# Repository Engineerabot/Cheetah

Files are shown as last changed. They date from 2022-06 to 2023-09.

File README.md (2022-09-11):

# README

Introducing Raza is an open source hardware and software engineering project.

## Why is this project important

We want to create inspirational experiences. We want to work where engineering meets art, perhaps more art than engineering. Creation has a way of making us and others feel good. 

## How do I get started

Thank you for considering helping us develop Introducing Raza! We can use your help! Whether you are an expert artist, expert engineer, or a beginner, we could use your help!

## Installation 

If you would like to help with mechanically designing Raza, then join the Mechanical Team.  Our mechanical repository is housed within this github repository.  After joining the Mechanical Team, we will grant you access to our repository.  [Cheetah](https://github.com/Engineerabot/Introducing-Raza).  
  
### Modelio

Download Modelio Open Source from [here](https://www.modelio.org/downloads/download-modelio.html).  Once installed, open Modelio, select file and switch the workspace to point at the Modelio folder within your project clone.

### Solidworks

We have transitioned to Solidworks from Fusion 360.  

## License
[GPLv3](https://www.gnu.org/licenses/gpl-3.0.en.html)

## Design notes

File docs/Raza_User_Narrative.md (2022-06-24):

# User Narrative

Chris has been watching the clock for the last 40 mins.  "Why do I even come to this class? I never get anything out of it,"  Chris wonders. "He might say something that I need to know though.  What if he asked me a question?  I have no idea what he's been talking about lately. It is dark back here, I wonder if he can even see me back here.  I should probably try to listen, or at least look like I'm listening.  If I left early I could go read the textbook and learn this stuff in half the time, that would be more helpful then just sitting here."   

Chris anxiously looks at the exit door.  "It's only 20 feet away.  On the count of three I'm going to get up and walk over to it.  One, two... but if I left early, everyone would watch me walk out.  The professor would surely stop the lecture and look at me.  What if I dropped something?  That'd be terrible.  Could I sink into the floor and slither out the door Grinch style?  Is that possible?  How did the Grinch slide along the ground like that?"  Chris can feel his hands getting sweaty as his anxiousness grows.  "If I wait for the end of class, someone might try to talk to me.  Then I would have to deal with people in the hallway too.  Augh, why did I come today!?"  

Finally the class ends.  The students get up and orderly leave the classroom.  Chris pretends to gather his books, and waits for the other students to file out of the classroom.  Careful not to make eye contact with anyone, he grabs his bag and makes his way to the exit.   

The hallway is unusually clear as Chris tries to make his way through without getting caught up in an awkward conversation.  He notices a group of students gathered around the atrium, which creates an easy path to the doors.  Chris makes a break for it.  Unusual movement within the atrium catches Chris's eye.  Looking through the crowd, he sees the most remarkable creature.  Wham!  Chris's bag hits the ground.  With his bag, Chris drops all of his anxieties, all of his insecurities, all of concerns.  He pushes his way through the crowd of students and comes eye to eye with, what looks like, a cheetah.   

The cheetah walks along the window with strength and power.  It demands complete control of its environment. Muscles flexing with every step, the spine and tail naturally moving back and forth. The long slender body ready to turn and pounce or turn and run at any moment.   It's unpredictability keeps everyone on edge, it's beauty keeps everyone entranced.  Chris follows it along the window, matching it step for step.  He is careful to keep a half step behind.  Chris admires the beauty of the body, the narrow waist, the broad chest, the black tear markings on the face, the long fur on the back of the neck.  "It's barely older than a cub," Chris whispers.  The eyes are the most powerful feature of all.  There is power and confidence deep in those eyes, power and confidence in its soul. 

Chris has never seen a real life cheetah before.  Why is it here?  How did it get here?  Chris didn't know and didn't care.  Looking closely, Chris notices that it is a mechanical robot.  It is really much more than a robot, it is a work of art.  It is mechanical work of art.  This intrigues Chris even more.  "Who was the artist?   The detail of the face, the smooth movement of the body, the muscle detail, it seems so complex, yet so simple.  It is more natural than robotic, more art than engineering."  Zach watches it as it walks up and down the atrium for what seems like 5 minutes.  Darkness has now set in on the atrium, making the cheetah harder to see.

Looking down at his watch, Chris walks over to his bag and looks down at it.  With a deep breath, he picks up his bag, throws it over his shoulder and walks off.   Although, now with more fire in his spirit, and more power and confidence in his soul.

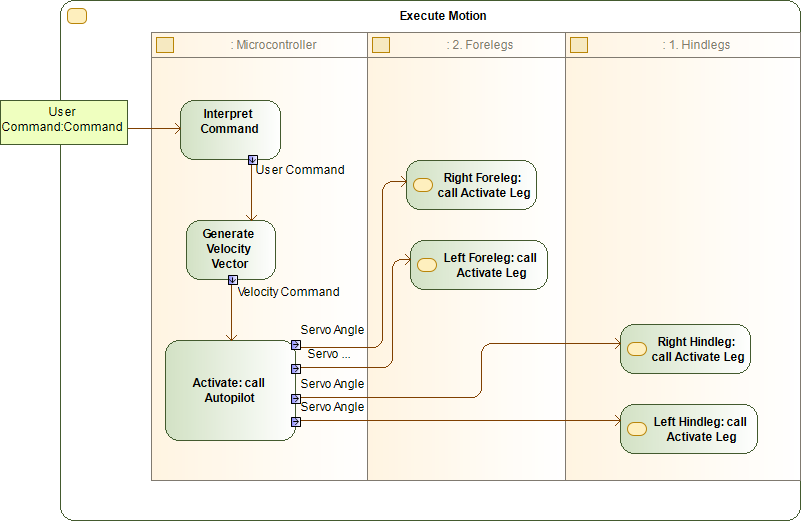
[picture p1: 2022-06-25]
modelio/Raza/doc/structure/img/4146f8e3-a1ea-4b1f-bf91-cede069ed973.png

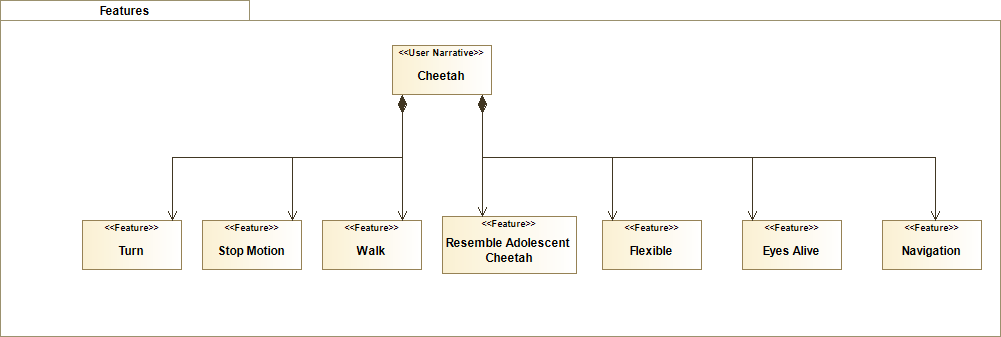
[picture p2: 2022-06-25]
modelio/Raza/doc/CheetahDoc/img/c8a9e4ff-c5fc-48f4-94d7-1af237ac6b6f.png

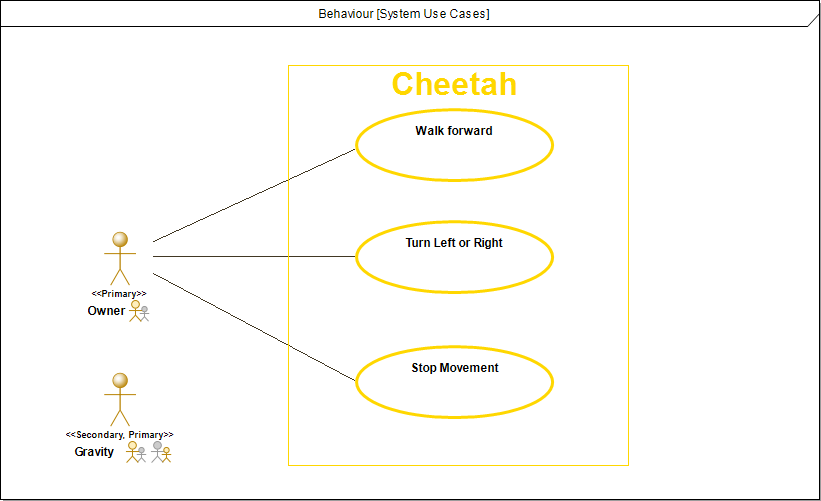
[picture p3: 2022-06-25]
modelio/Raza/doc/structure/img/6b453999-337c-4d21-a7c6-6fcb22df0617.png

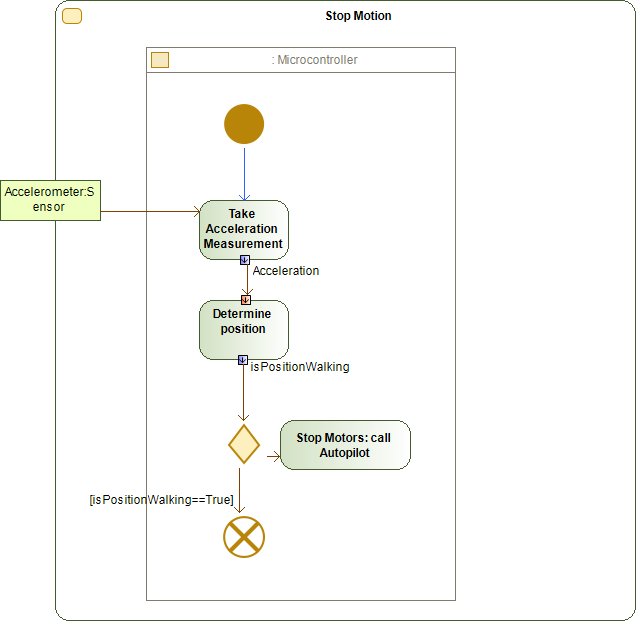
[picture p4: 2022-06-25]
modelio/Raza/doc/structure/img/0b002623-2319-4de4-a623-0d722e94e6e2.png

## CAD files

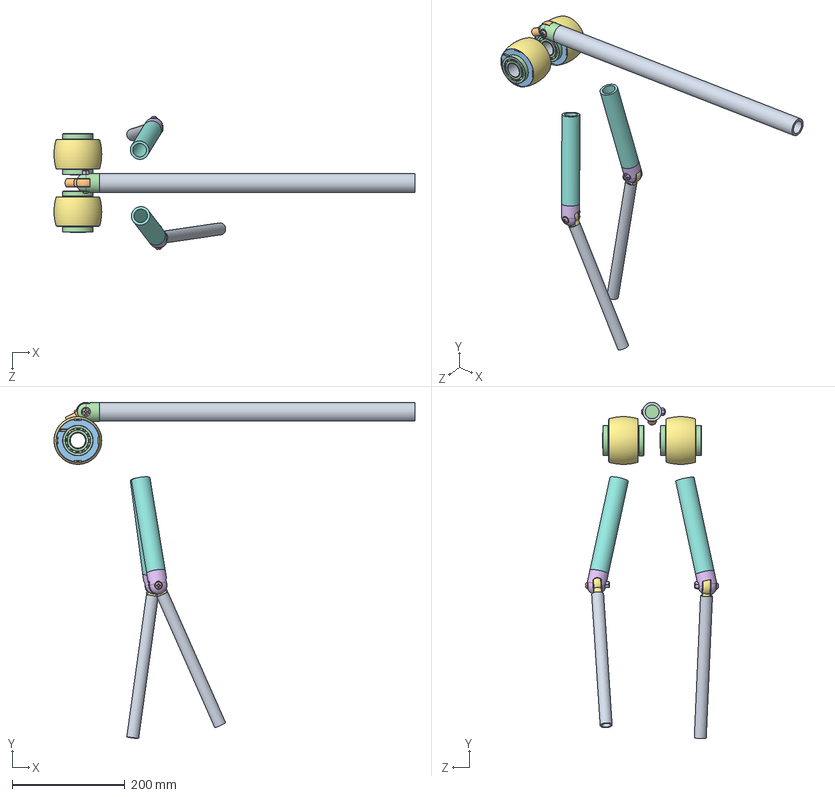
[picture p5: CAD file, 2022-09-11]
design/Level 1/Raza.SLDASM
639.2 x 595.4 x 236.1 mm
Spine
Inner Torso Joint
Knee Joint Pad x 6
Outer Torso Joint
90279A546_Steel Decorative Round Head Phillips Screws x 3
90640A129_Low-Strength Steel Nylon-Insert Locknut x 3
Outer Hip Joint x 2
Inner Hip Joint x 2
Hip Bar x 2
6910-2RS-EZO x 4
Hip Cap x 4
60355K211_Ball Bearing x 4
9271K664_Torsion Spring x 4
Outer Knee Joint x 2
Inner Knee Joint x 2
Femur x 2
Tibia x 2

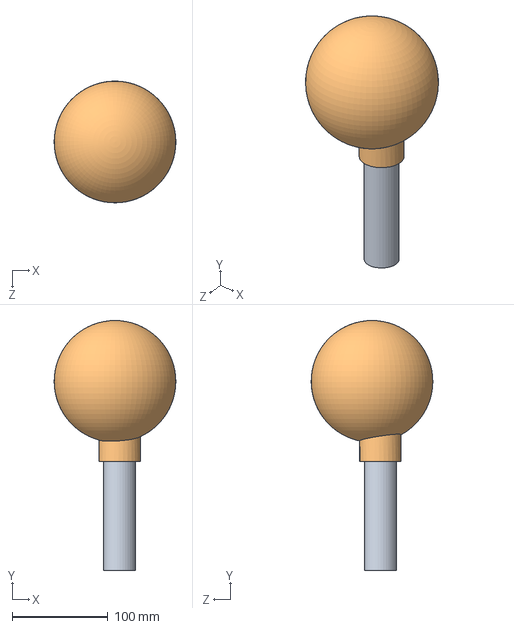
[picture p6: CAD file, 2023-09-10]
design/Level 2/Head Mechanics.SLDASM
127.0 x 260.8 x 126.9 mm
Neck
Skull

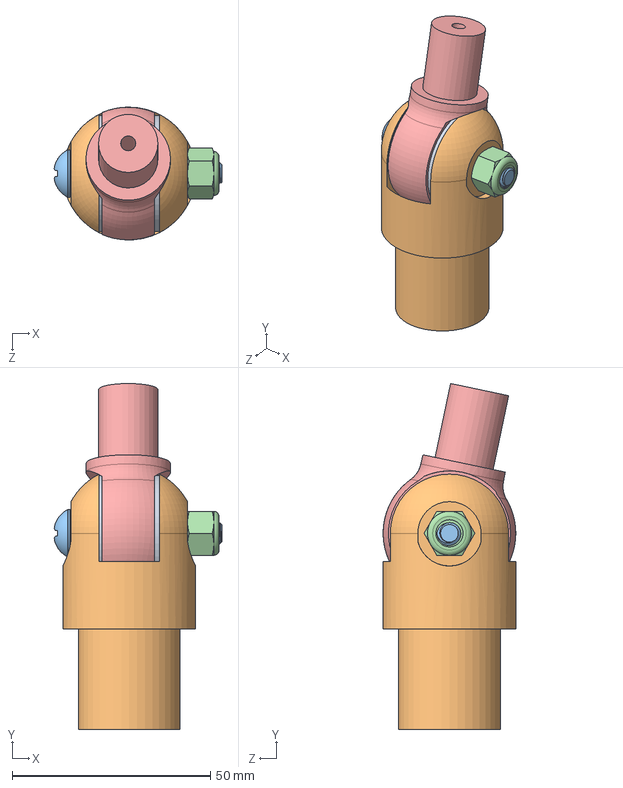
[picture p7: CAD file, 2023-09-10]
design/Level 3/Torso Joint.SLDASM
42.3 x 87.3 x 33.5 mm
Knee Joint Pad x 2
Outer Torso Joint
90279A546_Steel Decorative Round Head Phillips Screws
90640A129_Low-Strength Steel Nylon-Insert Locknut
Inner Torso Joint

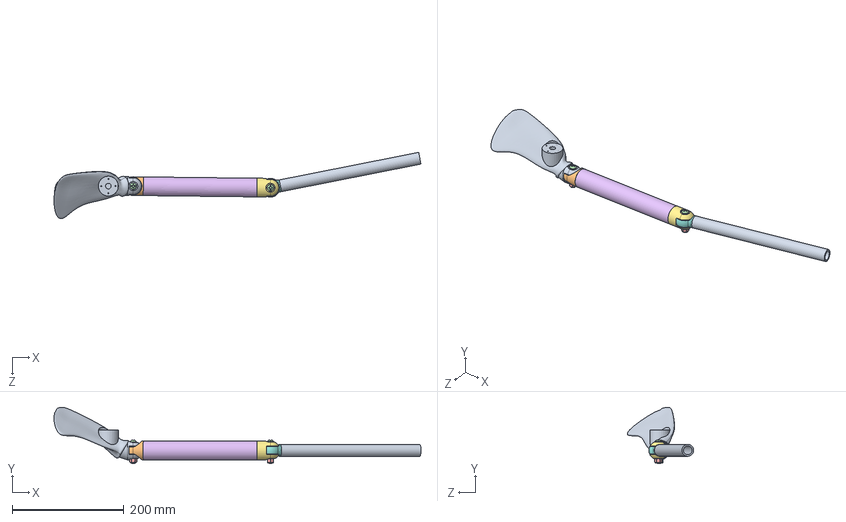
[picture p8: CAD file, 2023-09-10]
design/Level 2/Foreleg Mechanics - Left.SLDASM
655.8 x 100.7 x 118.4 mm
Scapula - Left
Inner Neck Joint
Knee Joint Pad x 4
90279A546_Steel Decorative Round Head Phillips Screws x 2
90640A129_Low-Strength Steel Nylon-Insert Locknut x 2
Humerus
Outer Torso Joint
Inner Torso Joint
Radius

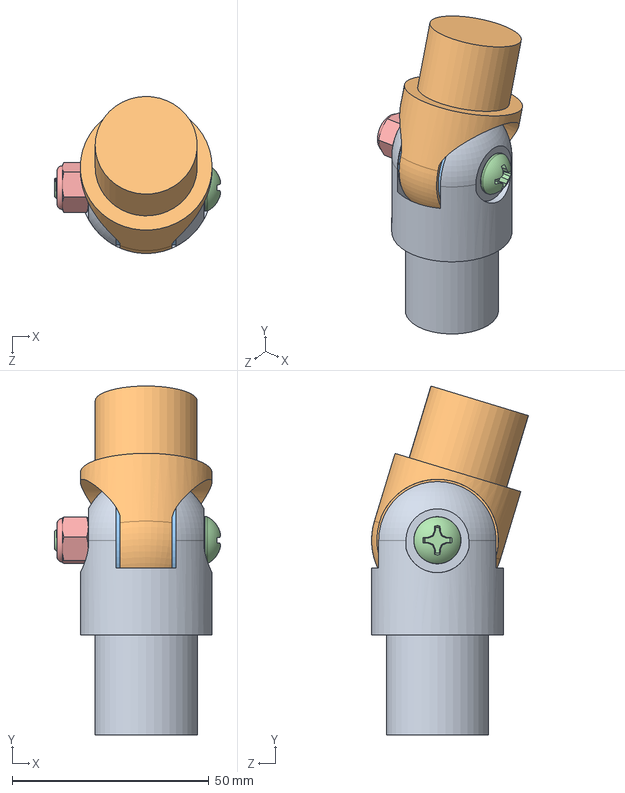
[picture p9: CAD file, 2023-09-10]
design/Level 3/Neck Joint.SLDASM
42.3 x 88.8 x 39.9 mm
Outer Torso Joint
Inner Neck Joint
Knee Joint Pad x 2
90279A546_Steel Decorative Round Head Phillips Screws
90640A129_Low-Strength Steel Nylon-Insert Locknut

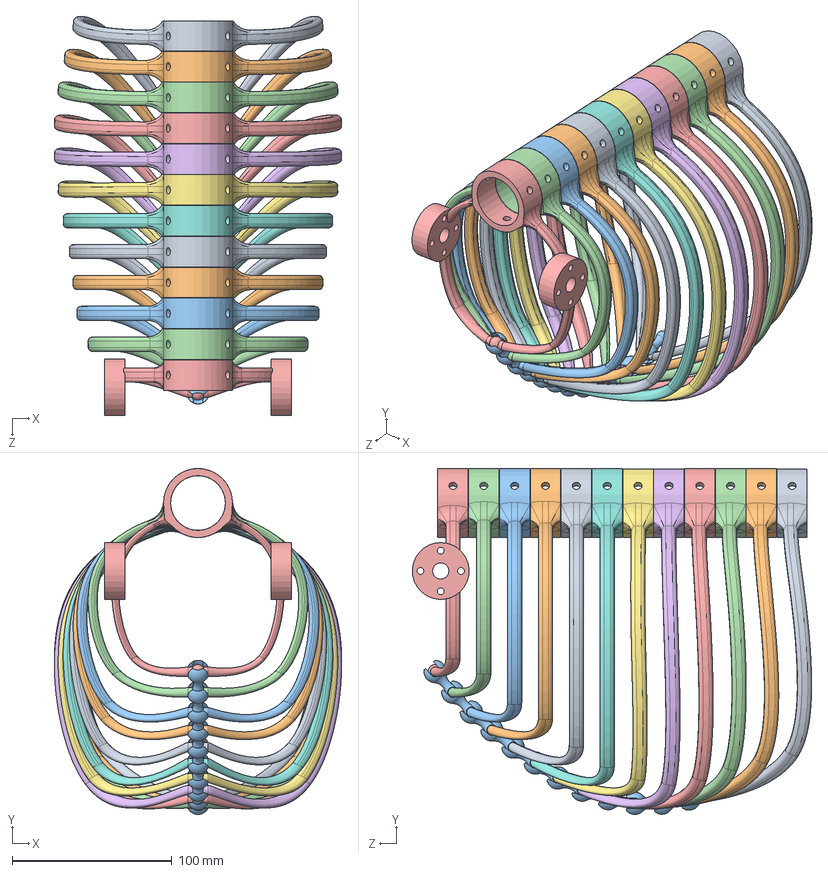
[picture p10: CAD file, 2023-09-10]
design/Level 3/Rib Cage.SLDASM
179.8 x 216.4 x 249.7 mm
Rib1
Rib2
Sternum x 12
Rib3
Rib4
Rib5
Rib6
Rib7
Rib8
Rib9
Rib10
Rib11
Rib12

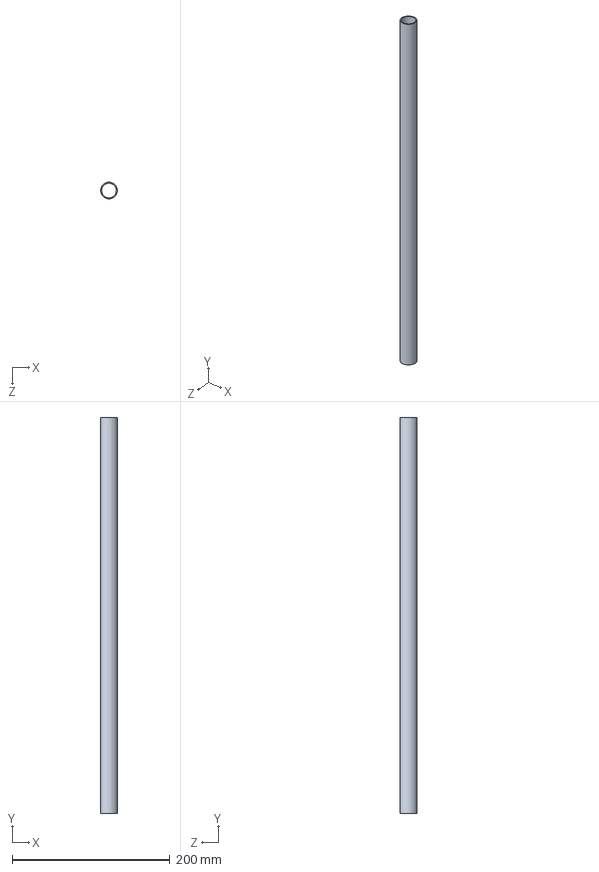
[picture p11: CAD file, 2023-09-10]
design/Level 2/Tail Mechanics.SLDASM
21.3 x 501.6 x 21.3 mm

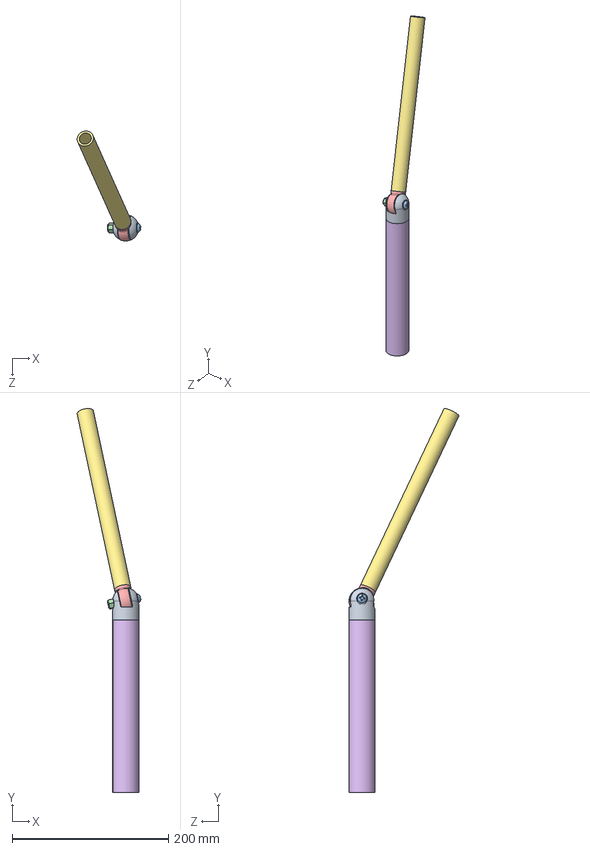
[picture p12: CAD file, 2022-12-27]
design/Level 2/Hind Leg Mechanics - Right.SLDASM
81.6 x 491.4 x 140.7 mm
Outer Knee Joint - Right
Knee Joint Pad x 2
90279A546_Steel Decorative Round Head Phillips Screws
90640A129_Low-Strength Steel Nylon-Insert Locknut
Inner Knee Joint
Femur
Tibia

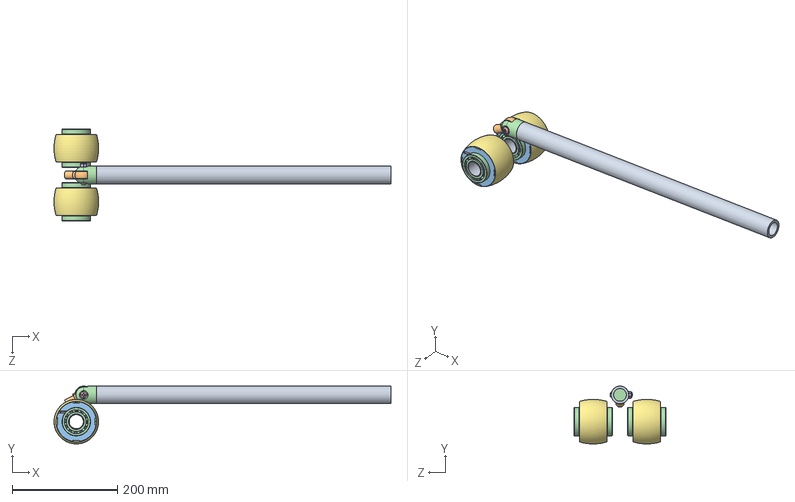
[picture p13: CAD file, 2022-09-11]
design/Level 2/Torso Mechanics.SLDASM
639.2 x 109.9 x 175.3 mm
Spine
Inner Torso Joint
Knee Joint Pad x 2
Outer Torso Joint
90279A546_Steel Decorative Round Head Phillips Screws
90640A129_Low-Strength Steel Nylon-Insert Locknut
Outer Hip Joint x 2
Inner Hip Joint x 2
Hip Bar x 2
6910-2RS-EZO x 4
Hip Cap x 4
60355K211_Ball Bearing x 4
9271K664_Torsion Spring x 4

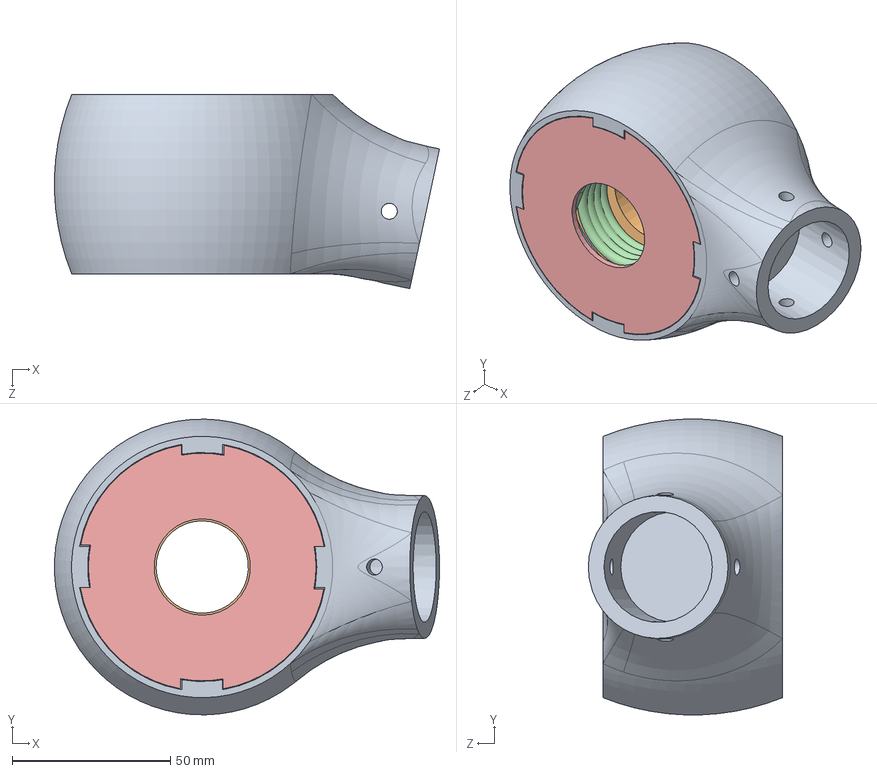
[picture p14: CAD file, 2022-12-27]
design/Level 3/Hip Joint.SLDASM
121.8 x 93.6 x 61.5 mm
Outer Hip Joint
Inner Hip Joint
6910-2RS-EZO x 2
9271K664_Torsion Spring x 2
Hip Cap x 2

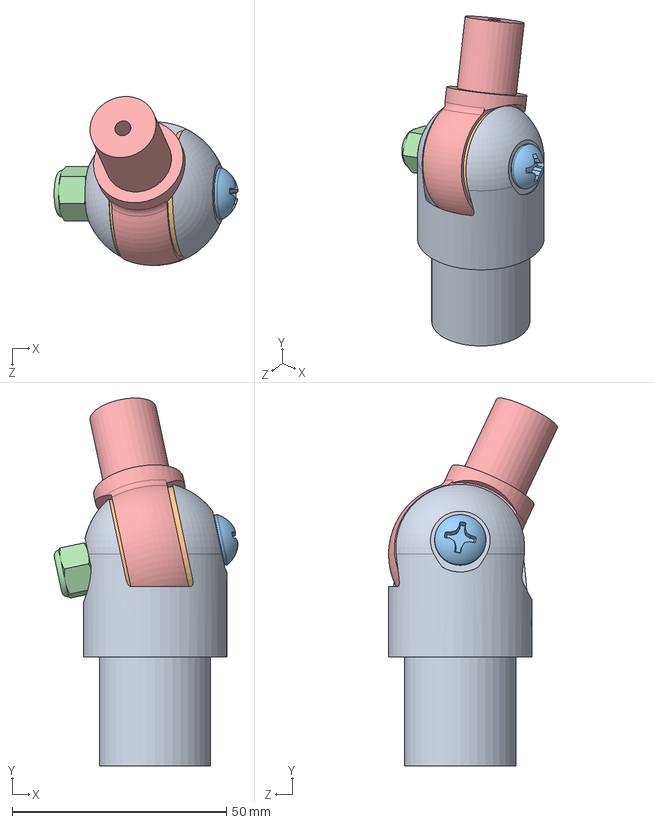
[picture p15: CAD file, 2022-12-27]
design/Level 3/Knee Joint - Right.SLDASM
42.9 x 85.9 x 39.4 mm
Outer Knee Joint - Right
Knee Joint Pad x 2
90279A546_Steel Decorative Round Head Phillips Screws
90640A129_Low-Strength Steel Nylon-Insert Locknut
Inner Knee Joint

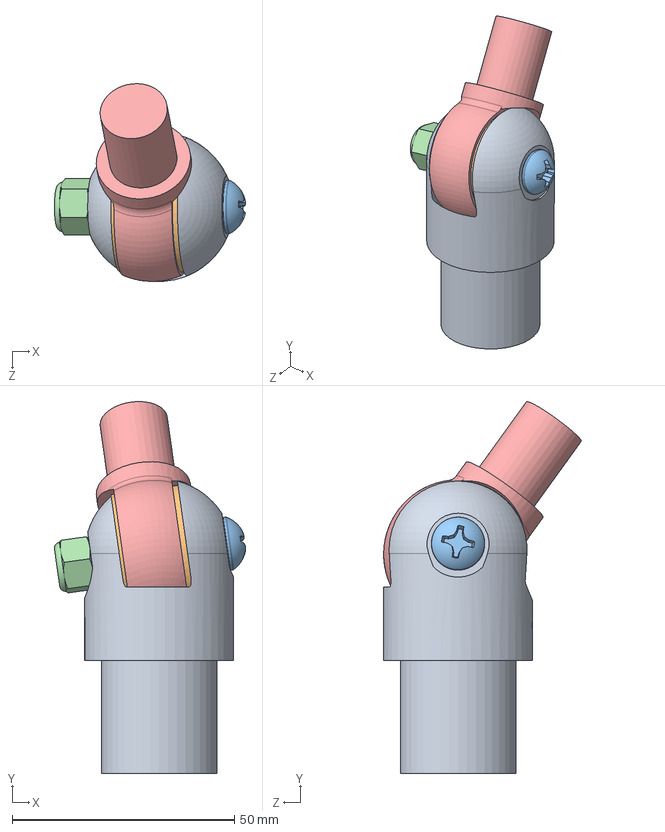
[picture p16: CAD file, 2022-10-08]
design/Level 3/Knee Joint - Right1.SLDASM
43.0 x 83.7 x 44.5 mm
Outer Knee Joint - Left
Knee Joint Pad x 2
90279A546_Steel Decorative Round Head Phillips Screws
90640A129_Low-Strength Steel Nylon-Insert Locknut
Inner Knee Joint

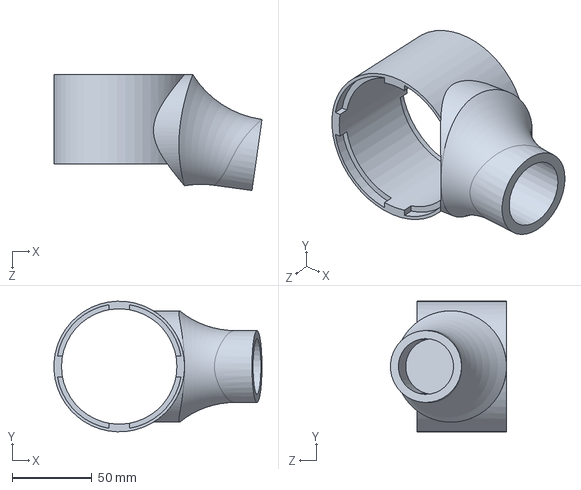
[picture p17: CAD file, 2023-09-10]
design/Level 4/Outer Hip Joint.SLDPRT
130.8 x 82.1 x 72.9 mm

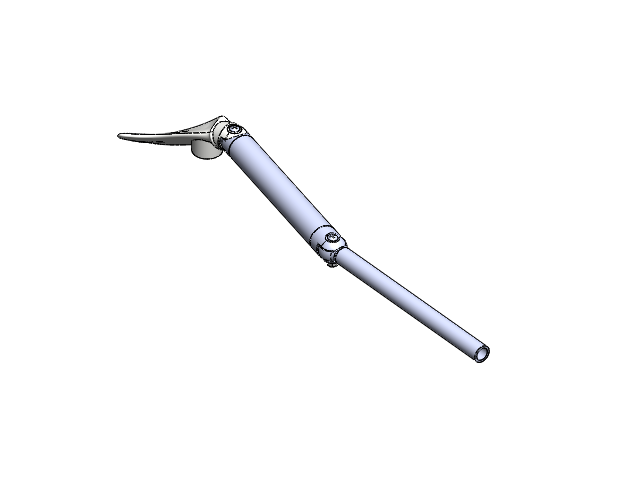
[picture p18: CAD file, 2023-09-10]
design/Level 2/Foreleg Mechanics - Right.SLDASM
Scapula - Right
Inner Neck Joint
Knee Joint Pad x 4
90279A546_Steel Decorative Round Head Phillips Screws x 2
90640A129_Low-Strength Steel Nylon-Insert Locknut x 2
Humerus
Outer Torso Joint
Inner Torso Joint
Radius

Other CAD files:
design/Level 3/Inner Knee Joint.SLDASM
design/Level 2/Hind Leg Mechanics - Left.SLDASM
design/Level 3/Knee Joint - Left.SLDASM
design/Level 3/Knee Joint.SLDASM
design/Level 4/638382_Mini_Econ_Gear.SLDPRT
design/Level 4/9271K597_Torsion Spring.SLDPRT
design/Level 4/9271K662_Torsion Spring.SLDPRT
design/Level 4/9271K664_Torsion Spring.SLDPRT
design/Level 4/9271K664_Torsion Spring2.SLDPRT
design/Level 4/Damper Torsion Shaft.SLDPRT
design/Level 4/DamperTorsionShaft.SLDPRT
design/Level 4/Femur.SLDPRT
design/Level 4/Hip Bar.SLDPRT
design/Level 4/Hip Cap.SLDPRT
design/Level 4/Humerus.SLDPRT
design/Level 4/Inner Hip Cap.SLDPRT
design/Level 4/Inner Hip Joint.SLDPRT
design/Level 4/Inner Hip Rotary Joint.SLDPRT
design/Level 4/Inner Knee Cap.SLDPRT
design/Level 4/Inner Knee Cover.SLDPRT
design/Level 4/Inner Knee Joint.SLDPRT
design/Level 4/Inner Knee.SLDPRT
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

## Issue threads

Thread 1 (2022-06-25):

Create next iteration of Torso-Hind Leg Joint

jhmeikle, 2022-06-25:
The Torso-Hind Leg Joint doesn't rotate as smoothly as it needs to, not sure why.  Update the mechanical design of the joint so it rotates smoothly.  It may be difficult to know if it rotates smooth or not until it is constructed.  This issue just covers the mechanical design.  This does not cover the assembly neither. @Engineerabot/mechanical

jhmeikle, 2022-06-28:
I updated this design and saved it off as Cheetah_Assemv113.  Need to prototype the design to see if it works or not.

jhmeikle, 2022-06-29:
I am going to reopen this issue.  I don't think it is very manufacturable, I think there is a better way to design it so it can be manufactured easier.

jhmeikle, 2022-06-30:
I redid this joint, and it looks much better.  It is far more simple, it is more elegant, and it'll be far easier to manufacture.  Check it out!
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

Closed 2022-06-30.

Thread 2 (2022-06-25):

Update the Hind Leg Joint Mount

jhmeikle, 2022-06-25:
The Hind Leg Joint Mount needs to be updated to match the updated hip joint.  It needs to be strong enough to support the leg as there could/should be a lot of force on it coming from the springs in the hip.  This will not be the final iteration of the design, just another step closer.  Update the hind leg joint mounts for both legs and attach them to the hip joints. @Engineerabot/mechanical

jhmeikle, 2022-06-30:
I updated this joint by adding it into the Torso-hip joint, it looks pretty good.
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

Closed 2022-06-30.

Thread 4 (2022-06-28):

Attach forelegs to torso at shoulder joint

jhmeikle, 2022-06-28:
Currently the scapula, which is also doubling as the shoulder joint is not connected to the torso.  It is just floating in space.
[Take a look](https://gmail1595039.autodesk360.com/g/shares/SH35dfcQT936092f0e43a3e646b28372f92f) . Connect the shoulder joint to the rib cage in such a way that will be structurally sound enough.  This will not be the long term solution, but it will work for this iteration.  In the future, there will be a joint similar to the hip joint, but we are still developing that.  For now, just connect the shoulder to the rib cage.  @Engineerabot/mechanical

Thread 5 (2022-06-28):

Manufacture hips and test

jhmeikle, 2022-06-28:
The hips need to be prototyped, tested, and feedback provided on how to better the design for the next iteration.  @Engineerabot/manufacturing

jhmeikle, 2022-07-10:
I manufactured this and tested it.  It went pretty well, it looks pretty good.  But there was a lot of play in the leg due to friction in the hip.  Plus one of the hips broke from the spring pushing its way through the 3d printed PLA.  The PLA needs to be strengthened.  Plus the glue was tough to work with, while it is probably strong enough, it was a pain because it bonded so quickly that it was tough to get it in the right position before it bonded.  So I probably need to work on that.  But the big problem was that the bearings had too much friction in them that the deadzone in the leg was too big.  I probably need to try to improve that.

Closed 2022-07-10.

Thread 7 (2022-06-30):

Optimize the Hip Bearings

jhmeikle, 2022-06-30:
Optimize the ball bearing within the hip by prototyping only the bearing.  Cut the hip down to include only the ball bearing, build it, tweak it, rebuild as necessary.  This is only to optimize the ball bearing, the ball bearing will still be fully integrated into the hip.  @Engineerabot/mechanical @Engineerabot/manufacturing

jhmeikle, 2022-07-08:
I created a bearing the right size for the Cheetah.  It took a few iterations of designing, manufacturing, and testing it before I got the dimensions right.  But I think I got it.

Closed 2022-07-08.

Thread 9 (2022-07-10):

New bearings in hips

jhmeikle, 2022-07-10:
Add new bearings in the hips to reduce friction and ultimately reduce the deadzone in the leg.

jhmeikle, 2022-07-23:
Updated hips with new bearings

Closed 2022-07-23.

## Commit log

2022-07-09 Adding Solidworks Design
    [90279A546_Steel Decorative Round Head Phillips Screws.STEP, 90640A129_Low-Strength Steel Nylon-Insert Locknut.STEP, Femur.SLDPRT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]
2022-07-09 Convert to Solidworks
    [90279A546_Steel Decorative Round Head Phillips Screws.SLDPRT, 90279A546_Steel Decorative Round Head Phillips Screws.STEP, 90640A129_Low-Strength Steel Nylon-In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]
2022-07-10 Continue to convert to solidworks
    [Inner Knee Joint.SLDPRT, Inner Torso Joint.SLDPRT, Outer Knee Joint.SLDPRT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]
2022-07-22 Update Torso and Hip Design
    [6010-2RS C3 Bearing.SLDPRT, 6910-2RS-EZO.SLDPRT, 9271K664_Torsion Spring.SLDPRT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]
2022-07-22 Moved Torso Mechanics to Level 2
    [Torso Mechanics.SLDASM]
2022-07-23 Angle Hindlegs outwards
    [Femur.SLDPRT, Hind Leg Mechanics.SLDASM, Hip Joint.SLDASM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]
2022-07-23 Update HIps to angle outwards
    [Hind Leg Mechanics.SLDASM, Hip Bar.SLDPRT, Hip Joint.SLDASM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]
2022-08-07 Update Hips and angle outwards
    Update Hips
    [43 RPM Econ Gear Motor.SLDPRT, Hind Leg Mechanics.SLDASM, Hip Bar.SLDPRT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]
2022-08-20 Update Pelvis
    [43 RPM Econ Gear Motor.SLDPRT, 60355K211_Ball Bearing.SLDPRT, 9271K664_Torsion Spring.SLDPRT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]
2022-08-21 Add body around Torso joint
    [Hip Cap.SLDPRT, Hip Joint.SLDASM, Outer Hip Joint.SLDPRT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]
2022-09-11 Add new Pelvis and add Level 5
    [43 RPM Econ Gear Motor.SLDPRT, 6010-2RS C3 Bearing.SLDPRT, 60355K211_Ball Bearing.SLDPRT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]
2022-09-11 Add Rib Cage
    [Hip Cap.SLDPRT, Hip Joint.SLDASM, Rib Cage.SLDASM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]
2022-09-17 Add new Pelvis and hindlegs
    [Foreleg Mechanics - Right.SLDASM, Foreleg Mechanics.SLDASM, Head Mechanics.SLDASM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]
2022-09-18 Add left and right hind legs
    [Femur.SLDPRT, Foreleg Mechanics - Left.SLDASM, Foreleg Mechanics - Right.SLDASM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]
2022-10-08 Update Hip Joint
    [6910-2RS-EZO.SLDPRT, Foreleg Mechanics - Left.SLDASM, Foreleg Mechanics - Right.SLDASM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]
2022-10-13 Printed Hip Joint
    Hip Joint looks good, but the knee disappeared?!
    [9271K597_Torsion Spring.SLDPRT, Head Mechanics.SLDASM, Hind Leg Mechanics - Left.SLDASM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]
2022-10-15 Clean up the knee joints
    [Head Mechanics.SLDASM, Hind Leg Mechanics - Left.SLDASM, Hind Leg Mechanics - Right.SLDASM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]
2022-11-26 Updated the Pelvis Design
    The pelvis design was updated, but may need to update the bearing to allow for the potentiometer.
    [6597K22_Rotary Speed Limiter.SLDPRT, Head Mechanics.SLDASM, Hip Bar.SLDPRT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]
2022-12-27 Add pelvis support for body attachment
    Add pelvis support
    [1302-0032-0025-motor mount.SLDPRT, 43 RPM Econ Gear Motor.SLDPRT, 6597K151_Rotary Speed Limiter.SLDPRT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]
2022-12-27 Update to newer version of SW
    [6910-2RS-EZO.SLDPRT, 90279A546_Steel Decorative Round Head Phillips Screws.SLDPRT, 90640A129_Low-Strength Steel Nylon-Insert Locknut.SLDPRT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]
2022-12-28 Update Hip with offset leg attachment
    [Hip.SLDASM, Outer Hip Joint.SLDPRT, Outer Pelvis Cap.SLDPRT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]
2022-12-29 Added pelvis to torso
    [Hip.SLDASM, Outer Hip Joint.SLDPRT, Outer Pelvis Cap.SLDPRT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]
2022-12-31 Add the knee joint
    [32 RPM Premium Gear Motor.SLDPRT, 60355K509_Ball Bearing.SLDPRT, 638382_Mini_Econ_Gear.SLDPRT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]
2023-09-10 Update to Hips
    Updated hips
    [9271K662_Torsion Spring.SLDPRT, Damper Torsion Shaft.SLDPRT, DamperTorsionShaft.SLDPRT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]
